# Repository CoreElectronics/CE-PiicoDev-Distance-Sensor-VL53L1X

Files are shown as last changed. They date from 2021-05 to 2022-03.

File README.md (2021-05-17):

# PiicoDev Distance Sensor VL53L1X

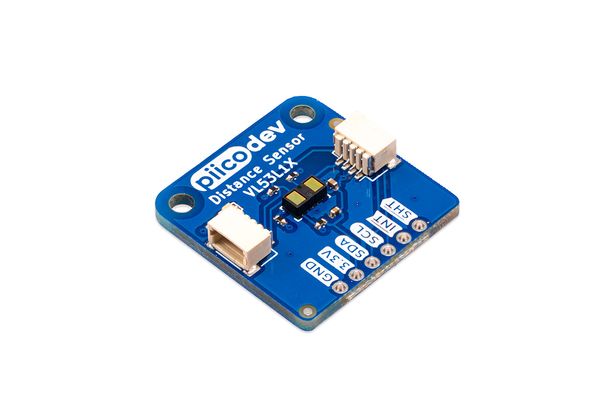
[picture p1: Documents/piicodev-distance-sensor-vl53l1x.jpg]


This is the repo for the [PiicoDev® Distance Sensor](https://core-electronics.com.au/catalog/product/view/sku/CE07741) PCB.

The PiicoDev® Distance Sensor is a long-distance laser-ranging sensor that uses Time-of-Flight (ToF) to accurately measure distances up to 4m.

- Small size, millimetre precision
- Can be protected behind many cover-window materials.
- PiicoDev connector, compatible with Qwiic and STEMMA QT (3.3V only)
- 2.54mm breakout for breadboarding/prototyping
- Manufactured and [supported](https://core-electronics.com.au/contacts/) in Australia by Core Electronics

# License
This project is open source - please review the LICENSE.md file for further licensing information.

If you have any technical questions, or concerns about licensing, please contact technical support on the [Core Electronics forums](https://forum.core-electronics.com.au/).

# Attribution
The hardware design of this module is influenced by the design from Sparkfun ([repo](https://github.com/sparkfun/Qwiic_Distance_VL53L1X)).

*\"PiicoDev\" and the PiicoDev logo are trademarks of Core Electronics Pty Ltd.*

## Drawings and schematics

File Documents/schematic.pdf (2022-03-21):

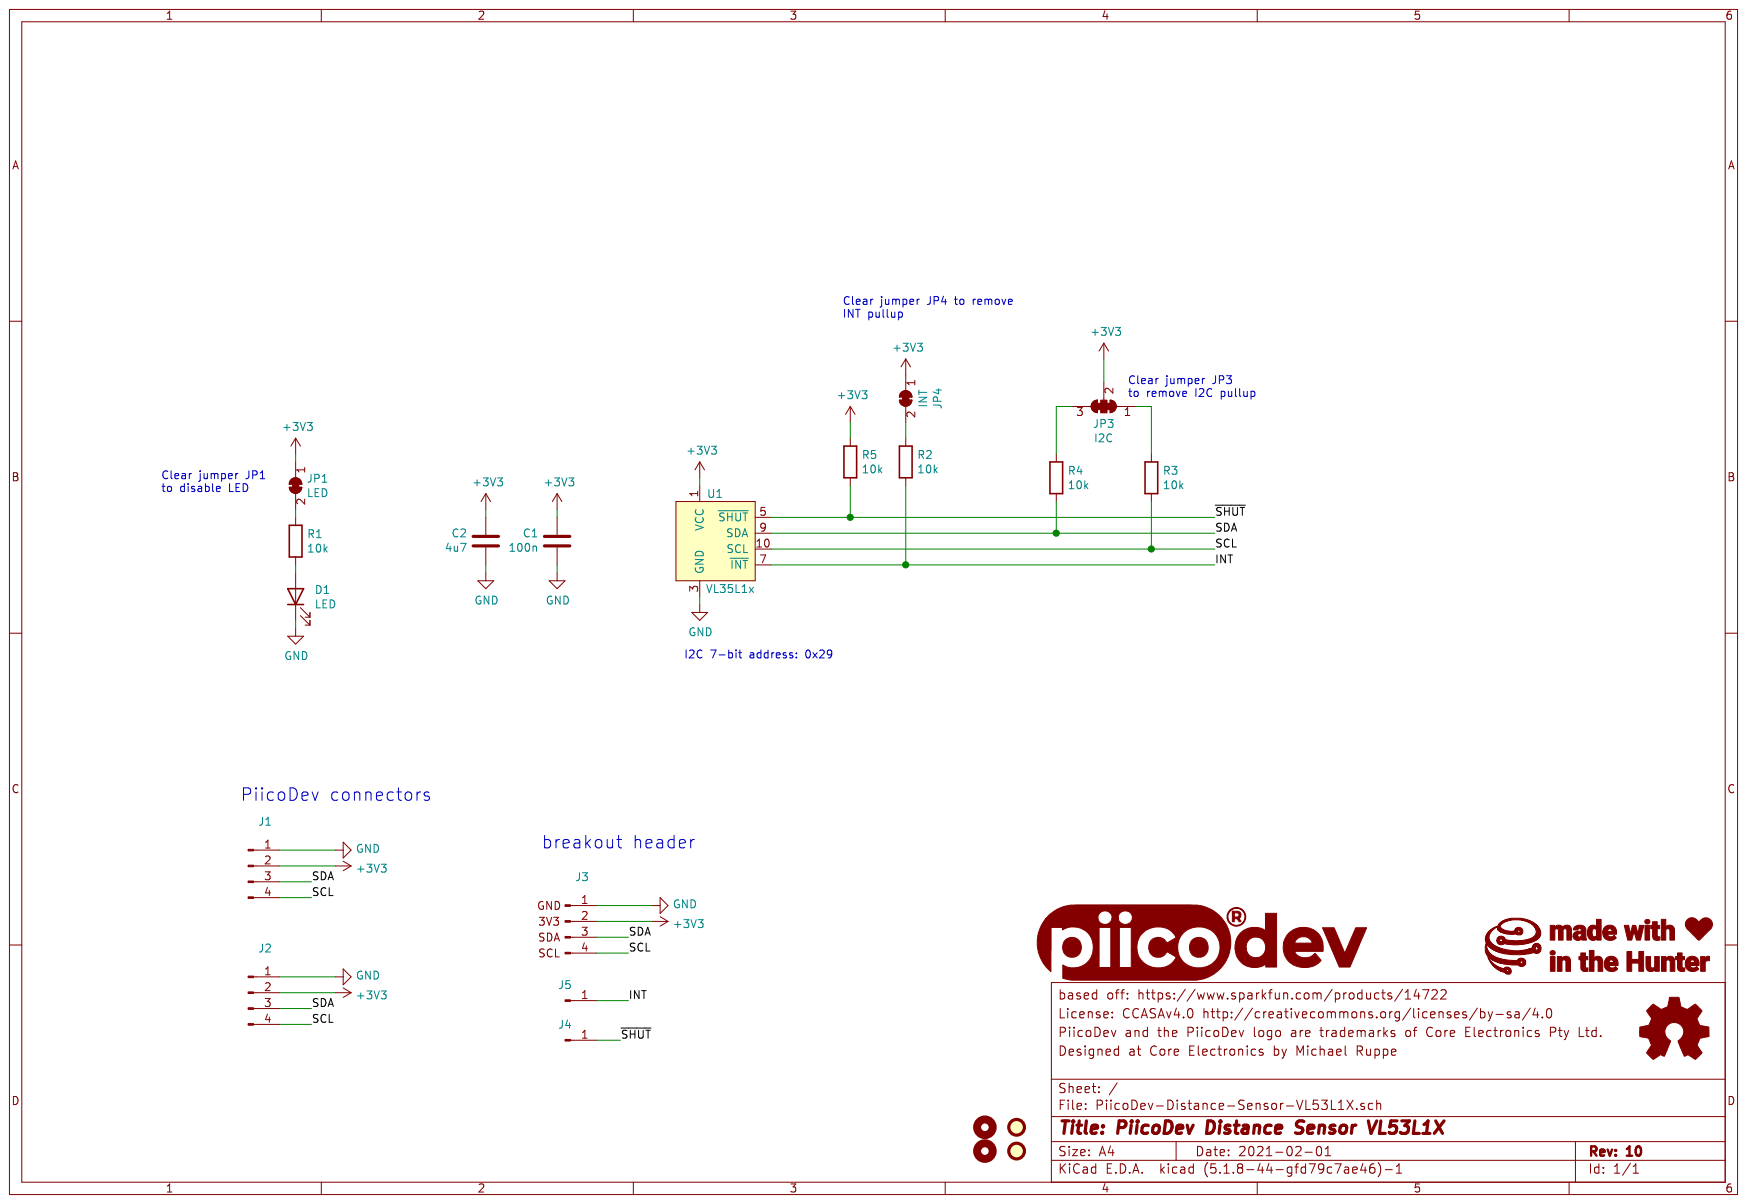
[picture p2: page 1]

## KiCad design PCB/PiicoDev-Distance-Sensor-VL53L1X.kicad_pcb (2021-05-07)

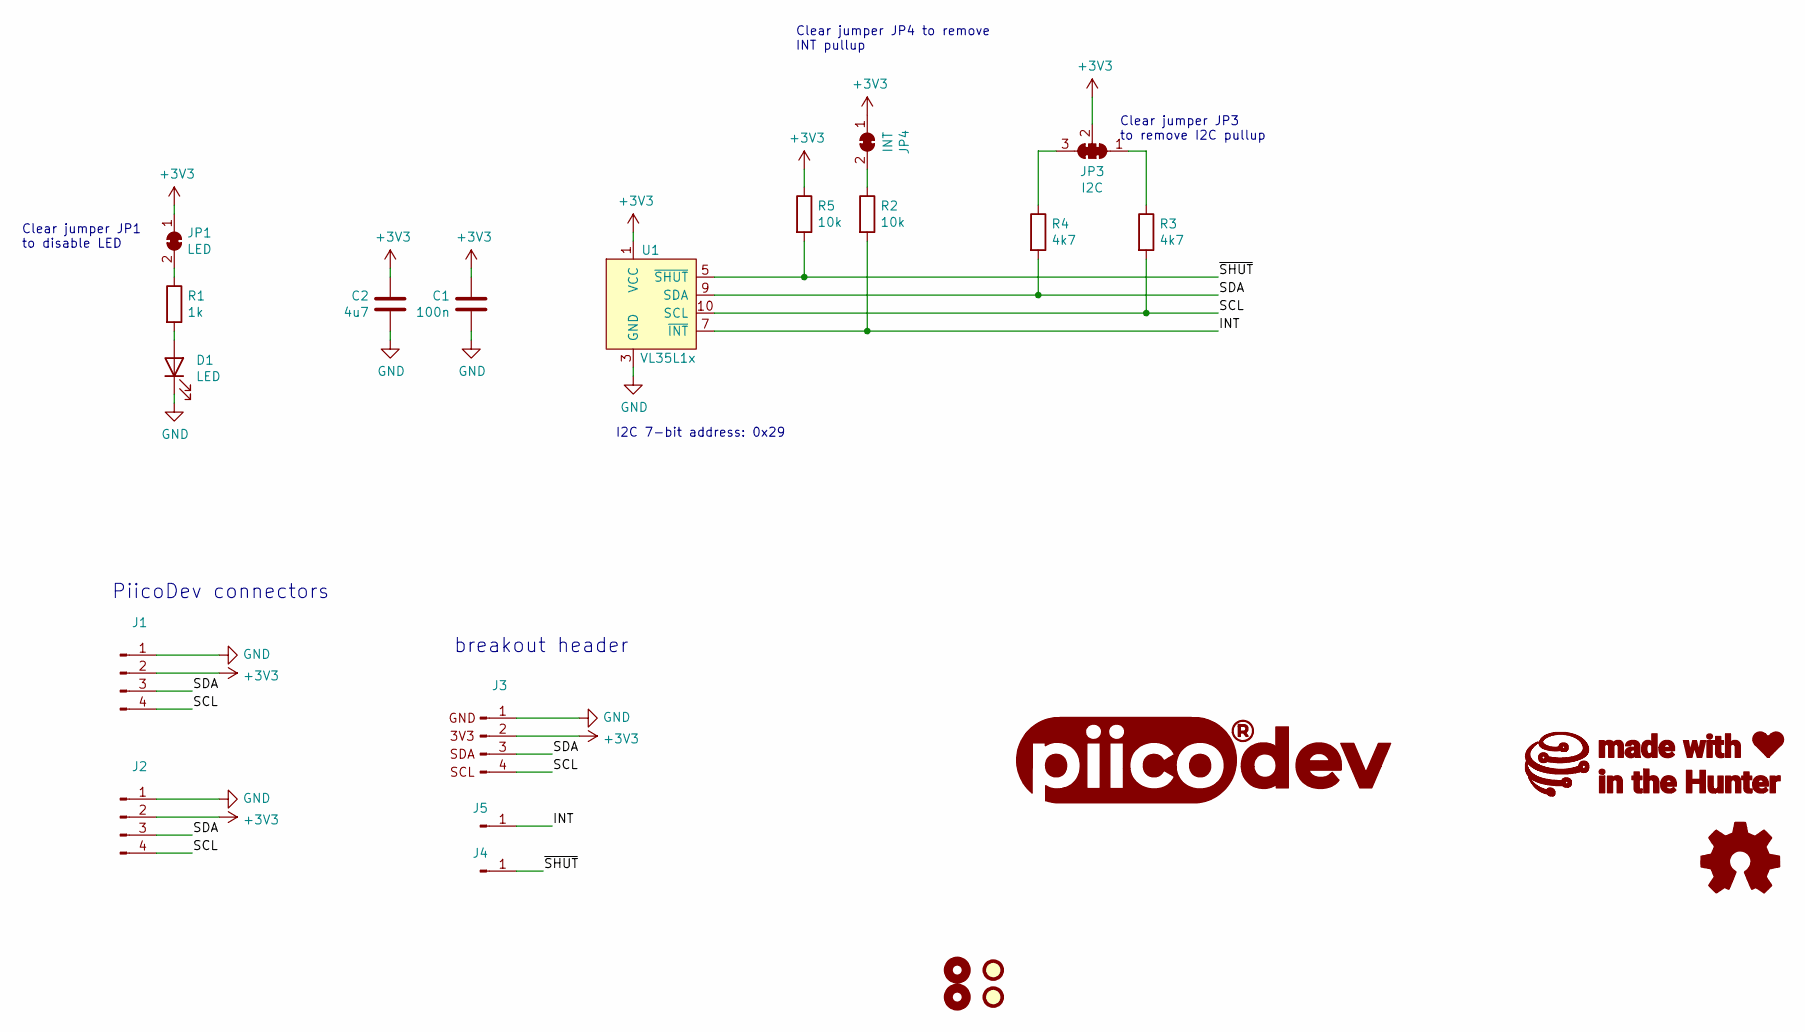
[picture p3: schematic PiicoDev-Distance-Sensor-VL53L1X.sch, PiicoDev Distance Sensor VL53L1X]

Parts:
C1: 100n; C_0402_1005Metric
C2: 4u7; C_0402_1005Metric
D1: LED; LED_0603_1608Metric
FID1, FID2: Fiducial; Fiducial_1mm_Mask2mm
G1: LOGO_CoreElectronics_made-with-love; piicodev_logo_14.2x3.4mm
G2: LOGO_piico; piicodev_logo_14.2x3.4mm
H1, H4: MountingHole; MountingHole_2.7mm_M2.5
J1, J2: JST_SH_SM04B-SRSS-TB_1x04-1MP_P1.00mm_Horizontal
J3: PiicoDev_header_4pin
J4: PinHeader_1x01_P2.54mm_Vertical
J5: PiicoDev_header_1pin_INT_uninverted
JP1: LED; SolderJumper-2_P1.3mm_Bridged_RoundedPad1.0x1.5mm
JP3: I2C; SolderJumper-3_P1.3mm_Closed_RoundedPad1.0x1.5mm_NumberLabe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
JP4: INT; SolderJumper-2_P1.3mm_Bridged_RoundedPad1.0x1.5mm
LOGO1: Logo_Open_Hardware_Small; oshw
R1: 1k; R_0402_1005Metric
R2, R5: 10k; R_0402_1005Metric
R3, R4: 4k7; R_0402_1005Metric
U1: VL35L1x; ST_VL53L1X

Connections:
+3V3: C1.2, C2.2, J1.2, J2.2, J3.2, JP1.1 (A), JP3.2 (C), JP4.1 (A), R5.1, U1.1 (VCC), U1.11 (VCC)
/INT: J5.1, R2.2, U1.7 (~INT)
/SCL: J1.4, J2.4, J3.4, R3.2, U1.10 (SCL)
/SDA: J1.3, J2.3, J3.3, R4.2, U1.9 (SDA)
/~SHUT: J4.1, R5.2, U1.5 (~SHUT)
GND: C1.1, C2.1, D1.1 (K), J1.1, J2.1, J3.1, U1.2 (GND), U1.3 (GND), U1.4 (GND), U1.6 (GND), U1.12 (GND)
unnamed: D1.2 (A), R1.2
unnamed: JP1.2 (B), R1.1
unnamed: JP3.1 (A), R3.1
unnamed: JP3.3 (B), R4.1
unnamed: JP4.2 (B), R2.1

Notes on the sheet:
Clear jumper JP1 to disable LED
Clear jumper JP3 to remove I2C pullup
PiicoDev connectors
breakout header
I2C 7-bit address: 0x29
Clear jumper JP4 to remove INT pullup

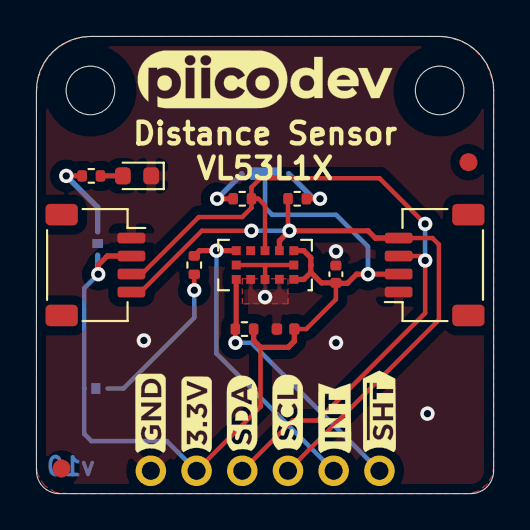
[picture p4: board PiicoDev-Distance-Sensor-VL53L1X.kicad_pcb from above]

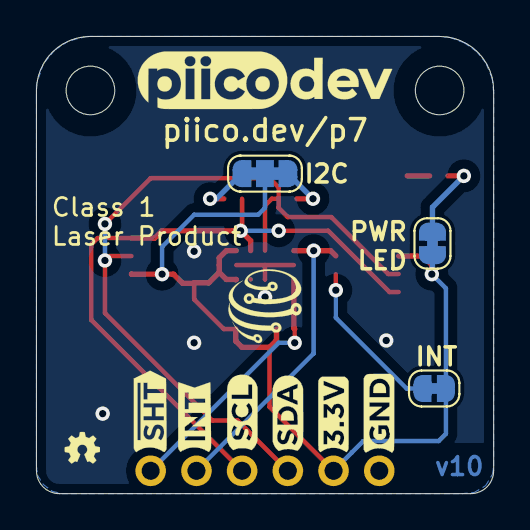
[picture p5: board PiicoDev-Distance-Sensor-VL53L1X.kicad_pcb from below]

Board: 2 copper layers, 25.4 x 25.4 mm, 24 parts (7 on the bottom side), 11 nets.

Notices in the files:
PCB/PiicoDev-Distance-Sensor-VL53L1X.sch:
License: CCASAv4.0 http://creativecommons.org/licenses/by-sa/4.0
